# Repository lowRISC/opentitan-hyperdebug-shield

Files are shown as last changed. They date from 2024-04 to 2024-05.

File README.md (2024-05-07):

# OpenTitan

OpenTitan logo

## About the project

See the [OpenTitan site](https://opentitan.org/) and [OpenTitan docs](https://opentitan.org/book) for more information about the project.

## About this repository

This repository contains the manufacturing files for the OpenTitan Hyperdebug Shield development platform, codenamed 'TEACUP' created as part of the OpenTitan project. It exists to enable collaboration across partners participating in the OpenTitan project.

### What is the OpenTitan Hyperdebug Shield?

hyp_ot

The OpenTitan Hyperdebug Shield, codenamed TEACUP, is a development board which connects to the STM32F552 Nucleo, (ST Part Number: [NUCLEO-L552ZE-Q](https://www.st.com/en/evaluation-tools/nucleo-l552ze-q.html). This development board allows for developing and provisioning of Nuvoton's implementation of OpenTitan, the NPCR100T.

The OpenTitan Hyperdebug Shield contains:
- 1x BOYD Corp. 718-SW08105-508-B1 9x9 0.5mm BGA socket (Socket Optional)
- 1x DEDIPROG TECHNOLOGY SOK-SPI-WSON68-L WSON68 flash socket (Socket Optional)
- 1x USBC, USB 2.0 connector (without PD/BC1.2)
- 2x MICROCHIP TECHNOLOGY INC. PAC1954T-E/4MX
- 1x ISSI IS31FL3205-QFLS4-TR LED Driver
- 4x RGB LEDs
- 4x Zio connectors
- 1x JTAG connector

### Block Diagram

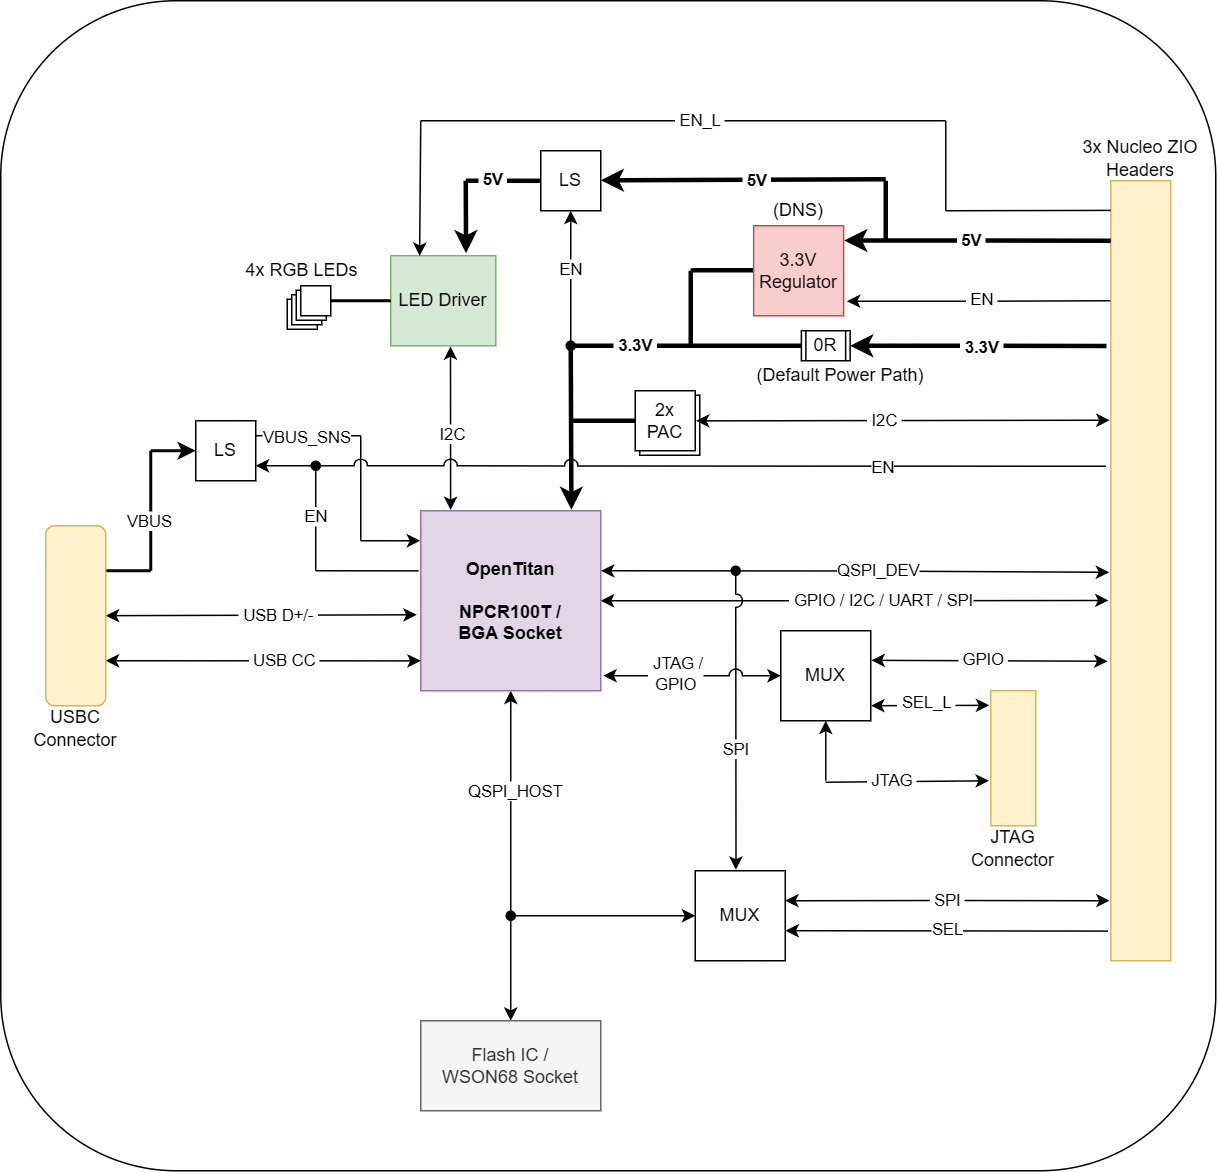
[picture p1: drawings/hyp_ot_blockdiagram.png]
hyp_ot_bd


Note: 
Sockets are provided for both the NPCR100T as well as the WSON8 flash. 
Both sockets are optional, giving the ability to have the NPCR100T as well as the WSON68 flash soldered down instead.

## Repository Directory

The project contains manufacturing documentation of the OpenTitan Hyperdebug Shield. 
For detailed documentation of the software and tooling, please see [docs.opentitan.org](https://docs.opentitan.org/).

### Projects top-level directory

    .
    ├── bom                     # Bill Of Materials
	├── drawings                # Schematics and Assembly Drawings
	├── gerbers                 # Gerbers, Drill Drawings and other output files for PCB Fab and Assembly
    ├── images                  # Images used on this repository
    └── README.md				# This file

## How to contribute

Have a look at [CONTRIBUTING](https://github.com/lowRISC/opentitan/CONTRIBUTING.md) and our [documentation on project organization and processes](./doc/project_governance/README.md) for guidelines on how to contribute code to this repository.

## Licensing

Unless otherwise noted, everything in this repository is covered by the Apache License, Version 2.0 (see [LICENSE](https://github.com/lowRISC/opentitan-hyperdebug-shield/LICENSE) for full text).

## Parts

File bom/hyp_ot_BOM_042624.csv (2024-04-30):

TITLE: Bill of Materials
DESIGN: hyp_ot
DATE: 04/26/2024
Ref Des | Qty | DESCR | MFGR | MFGR_PN | BOM_IGNORE
C24 | 1 | CAP, CER, X5R, 1uF, 10%, 10V, 0402, 0.55mm | ? | ? | DNS
C42 | 1 | CAP, CER, X5R, 1uF, 10%, 10V, 0402, 0.55mm | ? | ? | ?
C4,C7,C10,C13,C14,C15,C17,C18,C28,C29,C30,C31,C32,C34,C37 | 15 | CAP, CER, X7R, 0.1uF, 10%, 16V, 0402, 0.55mm | ? | ? | ?
C19,C23,C41 | 3 | CAP, CER, X7R, 0.1uF, 10%, 16V, 0402, 0.55mm | ? | ? | DNS
C20,C25,C33,C36,C38,C39,C40 | 7 | CAP, CER, X5R, 4.7uF, 20%, 10V, 0402, 0.65mm | ? | ? | ?
C27 | 1 | CAP, CER, X7R, 0.01uF, 10%, 25V, 0402, 0.56mm | ? | ? | DNS
C8 | 1 | CAP, CER, X7R, 0.01uF, 10%, 25V, 0402, 0.56mm | ? | ? | ?
C21,C22 | 2 | CAP, CER, X5R, 220pF, 10%, 25V, 0201, 0.33mm | ? | ? | DNS
C35 | 1 | CAP, CER, X5R, 4.7uF, 10%, 35V, 0603, 1.00mm | ? | ? | ?
J18 | 1 | CONN, HDR, VERT, 2x10 PIN, 2.54mmP, GOLD, SMD, 9.19mm | SAMTEC INC | HTST-110-01-L-DV-P-TR | ?
J1 | 1 | CONN, SKT, USB, TYPE C, RA, 24 PIN, 0.5mmP, GOLD, SMD, 3.38mm | AMPHENOL | 12401832E402A | ?
J21 | 1 | CONN, HDR, VERT, 6 PIN, 2.54mmP, GOLD, SMD, 5.84mm | SAMTEC INC | TSM-106-01-L-SV | DNS
J14,J22 | 2 | CONN, SKT, SMA, VERT, 1 PIN, 50R, GOLD, TH, 9.601mm | SAMTEC INC | SMA-J-P-H-ST-TH1 | DNS
J9,J10,J11,J12,J13,J15,J16 | 7 | CONN, HDR, UNSHRD, VERT, 1x2 PIN, 2.54mmP, TIN, TH, 8.73mm | FCI | 68000-402HLF | DNS
J19,J20 | 2 | CONN, B2B, SKT, RA, 2x6 PIN, 2.54mmP, GOLD, TH, 4.95mm | SAMTEC INC | SSW-106-02-F-D-RA | ?
J5 | 1 | CONN, SKT, SPI FLASH, WSON8 6x8, 8, 1.27mmP, Nickel/Gold, SMD, 9.85x10.20mm, 3.00mm | Dediprog Technology | SOK-SPI-WSON68-L | ?
CN8 | 1 | CONN, HDR, VERT, 2x8 PIN, 2.54mmP, GOLD, TH, 5.21mm | SAMTEC INC | TSW-108-16-G-D | ?
CN7 | 1 | CONN, HDR, VERT, 2x10 PIN, 2.54mmP, GOLD, TH, 5.31mm | SAMTEC INC | TSW-110-16-G-D | ?
CN9 | 1 | CONN, HDR, VERT, 2x15 PIN, 2.54mmP, GOLD, TH, 5.31mm | SAMTEC INC | TSW-115-16-G-D | ?
CN10 | 1 | CONN, HDR, VERT, 2x17 PIN, 2.54mmP, GOLD, TH 5.13mm | SAMTEC INC | TSW-117-16-G-D | ?
U8 | 1 | IC, AMP, R2R OUT, DUAL, 1.7-5.5Vin, 4.5mVoff, 450nA, VSSOP-8, 1.10mm | TEXAS INSTRUMENTS INC | TLV8802DGKR | DNS
U13,U15 | 2 | IC, LOGIC, LVC, BUFFER, TRI-STATE, AH ENABLE, 1.65-5.5Vcc, 3.4ns@5V/15pF, 32mA, SC70-5, 1.10mm | TEXAS INSTRUMENTS INC | SN74LVC1G126DCKR | ?
U14 | 1 | IC, LED DRIVER, RGB, 12-CH, I2C, 2.7-5.5V, Current 38 mA (max) QFN-20, 0.75mm | ISSI | IS31FL3205-QFLS4-TR | ?
U10,U11 | 2 | IC, ANALOG SW, MUX/DEMUX, 1:2, SPDT, 6-CH, 1.65-3.6Vcc, 100mA IS, 6.2Ohm MAX Ron, 240MHz, WQFN-24, 0.8mm | TEXAS INSTRUMENTS INC | TS3A27518ERTWR | ?
U1,U4 | 2 | IC, PWR, MONITOR, CURRENT, 4-CH, ADC, 16-BIT, I2C/SMBus, 2.7-5.5Vdd, QFN-16, 0.90mm | MICROCHIP TECHNOLOGY INC | PAC1954T-E/4MX | ?
U9 | 1 | IC, PWR, REG, LDO, AH ENABLE, 1.2-5.5Vin, 3.3Vout, 2%, 300mA, TSOT23-5, 1.00mm | Richtek Technology Corporation | RT9078-33GJ5 | DNS
U301 | 1 | IC, FLASH, NOR, SPI, 128Mb, 3.3V, WSON-8, 0.80mm | Winbond Electronics | W25Q128JVEIM | ?
DS5,DS9,DS10,DS11 | 4 | LED, RGB, R-619/G-518/B-467nm, R-450/G-710/B-140mcd, 120 DEG, R-1.8V/G-2.8V/B-2.8V@20mA, SMD-6, 1.6x1.6mm, 0.60mm | Everlight Electronics Co., Ltd | 19-337C/RSBHGHC-A91/4T | ?
U12 | 1 | IC, PWR, LOAD SW, AH ENABLE, 1.05-5.5Vin, 2A, 37mOhm@5Vin/200mA, DSBGA-4, 0.50mm | TEXAS INSTRUMENTS INC | TPS22915BYFPR | DNS
U7 | 1 | IC, PWR, LOAD SW, AH ENABLE, 1.05-5.5Vin, 2A, 37mOhm@5Vin/200mA, DSBGA-4, 0.50mm | TEXAS INSTRUMENTS INC | TPS22915BYFPR | ?
D4,D6 | 2 | DIODE, TVS, BI, ESD PROT, 5Vrwm, 10Vbr, 12.8Vcl, 2A Ipp, 6pF, SOD962-2, 0.32mm | Nexperia | PESD5V0V1BDSF,315 | ?
R62,R63,R66,R67,R109,R110 | 6 | RES, 0.0, 1/20W, 0201, 0.26mm | ? | ? | DNS
R69,R70,R119,R153,R154 | 5 | RES, 0.0, 1/20W, 0201, 0.26mm | ? | ? | ?
R107,R115 | 2 | RES, 10K, 5%, 1/20W, 0201, 0.26mm | ? | ? | DNS
R163,R164,R165,R166,R167,R168,R169 | 7 | RES, 0.0, 1/16W, 0402, 0.40mm | ? | ? | ?
R17,R24,R26,R59,R146,R175 | 6 | RES, 1M, 1%, 1/10W, 0603, 0.60mm | ? | ? | ?
R97 | 1 | RES, 100, 1%, 1/16W, 0402, 0.40mm | ? | ? | DNS
R23,R25,R27,R155 | 4 | RES, 4.99K, 1%, 1/16W, 0402, 0.40mm | ? | ? | ?
R118,R160 | 2 | RES, 22, 5%, 1/16W, 0402, 0.40mm | ? | ? | ?
R68,R71 | 2 | RES, 2M, 5%, 1/16W, 0402, 0.40mm | ? | ? | DNS
R44,R47,R122 | 3 | RES, 100K, 1%, 1/10W, 0603, 0.55mm | ? | ? | ?
R170,R190 | 2 | RES, 100K, 1%, 1/10W, 0603, 0.55mm | ? | ? | DNS
R7,R11,R14,R15,R18,R19,R21,R22,R135,R136 | 10 | RES, 1K, 1%, 1/10W, 0603, 0.60mm | ? | ? | ?
R42,R43,R48,R49,R50,R51,R58,R75,R76,R77,R78,R83,R84,R85,R86,R87,R93,R95,R96,R100,R101,R105,R106,R113,R117,R143,R151,R162,R176,R192 | 30 | RES, 0.0, 1/10W, 0603, 0.60mm | ? | ? | ?
R116,R150,R191 | 3 | RES, 0.0, 1/10W, 0603, 0.60mm | ? | ? | DNS
R64,R65 | 2 | RES, 5.11K, 1%, 1/16W, 0402, 0.40mm | ? | ? | DNS
R173 | 1 | RES, 7.5K, 1%, 1/16W, 0402, 0.40mm | ? | ? | ?
R120,R121,R125,R134,R145 | 5 | RES, 10K, 5%, 1/10W, 0603, 0.55mm | ? | ? | DNS
R123,R124,R131,R139,R140,R142,R161,R174,R189,R193 | 10 | RES, 10K, 5%, 1/10W, 0603, 0.55mm | ? | ? | ?
R177,R179,R180,R182,R183,R185,R186,R188 | 8 | RES, 33, 5%, 1/10W, 0603, 0.55mm | ? | ? | ?
R41,R114 | 2 | RES, 499, 1%, 1/10W, 0603, 0.55mm | ? | ? | ?
R178,R181,R184,R187 | 4 | RES, 75, 0.1%, 1/10W, 0603, 0.55mm | ? | ? | ?
R79,R80,R81,R82,R91,R94 | 6 | RES, 0.5, 1%, 1/10W, 0603, 0.60mm | ? | ? | ?
Q9,Q10 | 2 | XSTR, MOSFET, N-CH, DUAL, 50Vds, 200mA Id, 6 Ohm@1.8Vgs/10mA, 300mW, 6pF, SOT563-6, 0.60mm | DIODES INC. | DMN5L06VK-7 | ?
D1,D2 | 2 | DIODE, ZENER, 0.9Vf @ 10mA, 5.6Vz, 5%, 50uA Izt, 300mW, SOD323, 1.1mm | Nexperia | BZX38450-C5V6 | DNS
D5 | 1 | DIODE, ZENER, 0.9Vf @ 10mA, 5.6Vz, 5%, 50uA Izt, 300mW, SOD323, 1.1mm | Nexperia | BZX38450-C5V6 | ?
U2 | 1 | Mating BGA socket for G660-00537-00 | Nuvoton Technology | NPCR100T | ?
 | 196

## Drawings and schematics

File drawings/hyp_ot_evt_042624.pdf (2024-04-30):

D

7

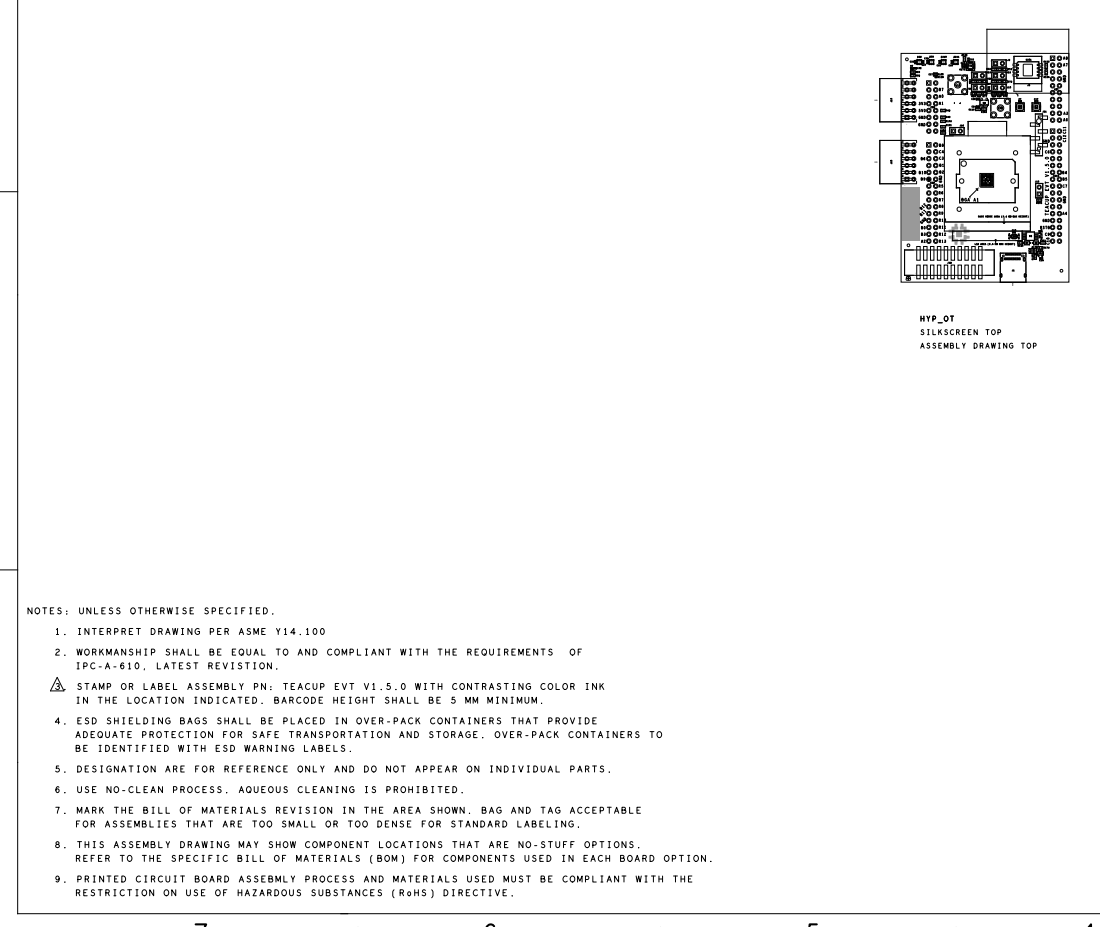
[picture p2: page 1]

INITIAL
CHANGED ASSEMBLY NPTE WITH G650 P/N
EVT UPREV WITH BUG AND DESIGN FIX

BASE HINGE AREA (3,4 MM MAX HEIGHT)

LID AREA (6.4 MM MAX HEIGHT)

NOTES: UNLESS OTHERWISE SPECIFIED.

1. INTERPRET DRAWING PER ASME Y14.100

3. STAMP OR LABEL ASSEMBLY PN: TEACUP EVT V1.5.0 WITH CONTRASTING COLOR INK

IN THE LOCATION INDICATED. BARCODE HEIGHT SHALL BE 5 MM MINIMUM.

4. ESD SHIELDING BAGS SHALL BE PLACED IN OVER-PACK CONTAINERS THAT PROVIDE

ADEQUATE PROTECTION FOR SAFE TRANSPORTATION AND STORAGE. OVER-PACK CONTAINERS TO

BE IDENTIFIED WITH ESD WARNING LABELS.

5. DESIGNATION ARE FOR REFERENCE ONLY AND DO NOT APPEAR ON INDIVIDUAL PARTS.

6. USE NO-CLEAN PROCESS. AQUEOUS CLEANING IS PROHIBITED.

7. MARK THE BILL OF MATERIALS REVISION IN THE AREA SHOWN. BAG AND TAG ACCEPTABLE

FOR ASSEMBLIES THAT ARE TOO SMALL OR TOO DENSE FOR STANDARD LABELING.

8. THIS ASSEMBLY DRAWING MAY SHOW COMPONENT LOCATIONS THAT ARE NO-STUFF OPTIONS.

REFER TO THE SPECIFIC BILL OF MATERIALS (BOM) FOR COMPONENTS USED IN EACH BOARD OPTION.

9. PRINTED CIRCUIT BOARD ASSEBMLY PROCESS AND MATERIALS USED MUST BE COMPLIANT WITH THE

RESTRICTION ON USE OF HAZARDOUS SUBSTANCES (RoHS) DIRECTIVE.

D

7

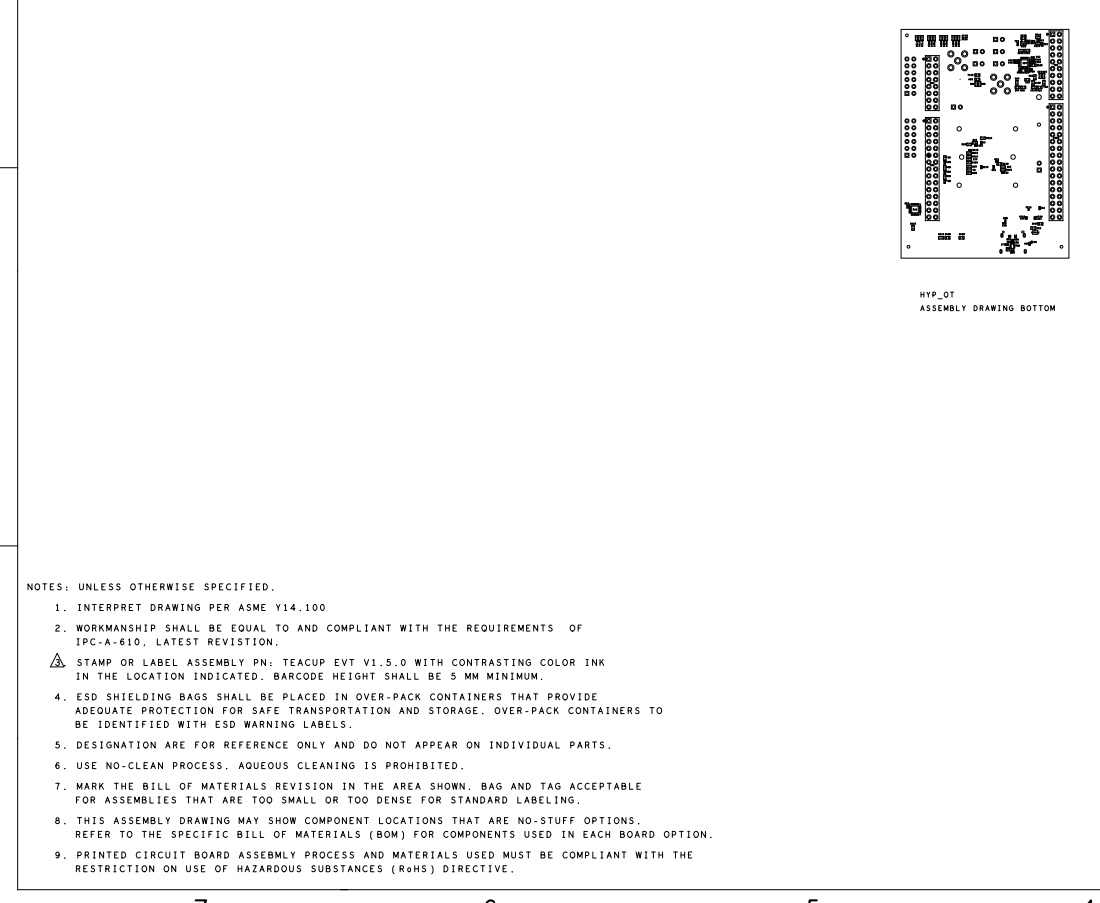
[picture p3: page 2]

INITIAL
CHANGED ASSEMBLY NPTE WITH G650 P/N
EVT UPREV WITH BUG AND DESIGN FIX

NOTES: UNLESS OTHERWISE SPECIFIED.

1. INTERPRET DRAWING PER ASME Y14.100

3. STAMP OR LABEL ASSEMBLY PN: TEACUP EVT V1.5.0 WITH CONTRASTING COLOR INK

IN THE LOCATION INDICATED. BARCODE HEIGHT SHALL BE 5 MM MINIMUM.

4. ESD SHIELDING BAGS SHALL BE PLACED IN OVER-PACK CONTAINERS THAT PROVIDE

ADEQUATE PROTECTION FOR SAFE TRANSPORTATION AND STORAGE. OVER-PACK CONTAINERS TO

BE IDENTIFIED WITH ESD WARNING LABELS.

5. DESIGNATION ARE FOR REFERENCE ONLY AND DO NOT APPEAR ON INDIVIDUAL PARTS.

6. USE NO-CLEAN PROCESS. AQUEOUS CLEANING IS PROHIBITED.

7. MARK THE BILL OF MATERIALS REVISION IN THE AREA SHOWN. BAG AND TAG ACCEPTABLE

FOR ASSEMBLIES THAT ARE TOO SMALL OR TOO DENSE FOR STANDARD LABELING.

8. THIS ASSEMBLY DRAWING MAY SHOW COMPONENT LOCATIONS THAT ARE NO-STUFF OPTIONS.

REFER TO THE SPECIFIC BILL OF MATERIALS (BOM) FOR COMPONENTS USED IN EACH BOARD OPTION.

9. PRINTED CIRCUIT BOARD ASSEBMLY PROCESS AND MATERIALS USED MUST BE COMPLIANT WITH THE

RESTRICTION ON USE OF HAZARDOUS SUBSTANCES (RoHS) DIRECTIVE.

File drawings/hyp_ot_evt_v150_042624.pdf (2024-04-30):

## THIS BOARD CONNECTS TO A MAINBOARD USING ZIO HEADERS CN7-CN10

## NOTES:

## MAIN POWER IS SOURCED FROM THE MAINBOARD THROUGH CN8

## TABLE OF CONTENTS

# (TEACUP)

# OpenTitan Hyperdebug Shield

2 | OPENTITAN
3 | SPI FLASH
4 | USB CONN
5 | LED DRIVER
6 | CURRENT SENSE
7 | HEADERS

1

| PAGE TABLE OF CONTENTS TITLE:
DESIGN: | DOC NUMBER: EVT-150-SCH | REV: 1.5.0
| AUTHOR: | PAGE: 1 OF 7 Brendan Bleker 1 OF 7 Thu Apr 11 17:03:11 2024
SHEET NO. | SHEET NAME

# TABLE OF CONTENTS

MODIFIED: LICENSED UNDER THE APACHE LICENSE, VERSION 2.0, SEE LICENSE.TXT FOR DETAILS.
1 | 5 | 7 | 13
15 | FLAT:

H

A

K | K
J | J
4 | 6 | 8 | 9
1 | 2 | 3 | 5 | 6 | 7 | 8 | 10 | 11 | 12 | 13 | 14 | 16

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
SPDX-LICENSE-IDENTIFIER: APACHE-2.0

COPYRIGHT LOWRISC CONTRIBUTORS.

## BGA SOCKET

## 718-SW08105-508-B1

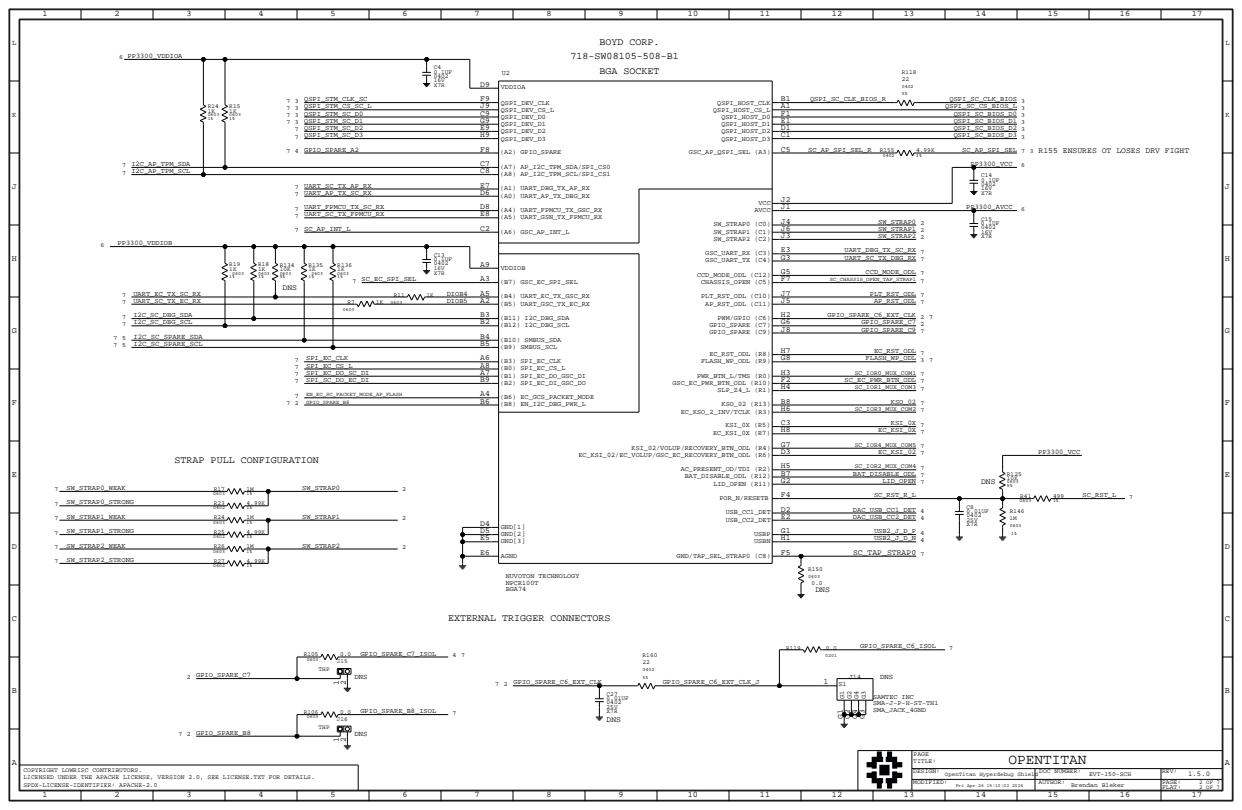
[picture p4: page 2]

OPENTITAN

OpenTitan Hyperdebug Shield
Brendan Bleker | 2 OF 7 Fri Apr 26 15:10:02 2024

TRACES TO REDUCE STUBS.

## TO PREVENT BOTH FROM BEING POPULATED AT THE SAME TIME

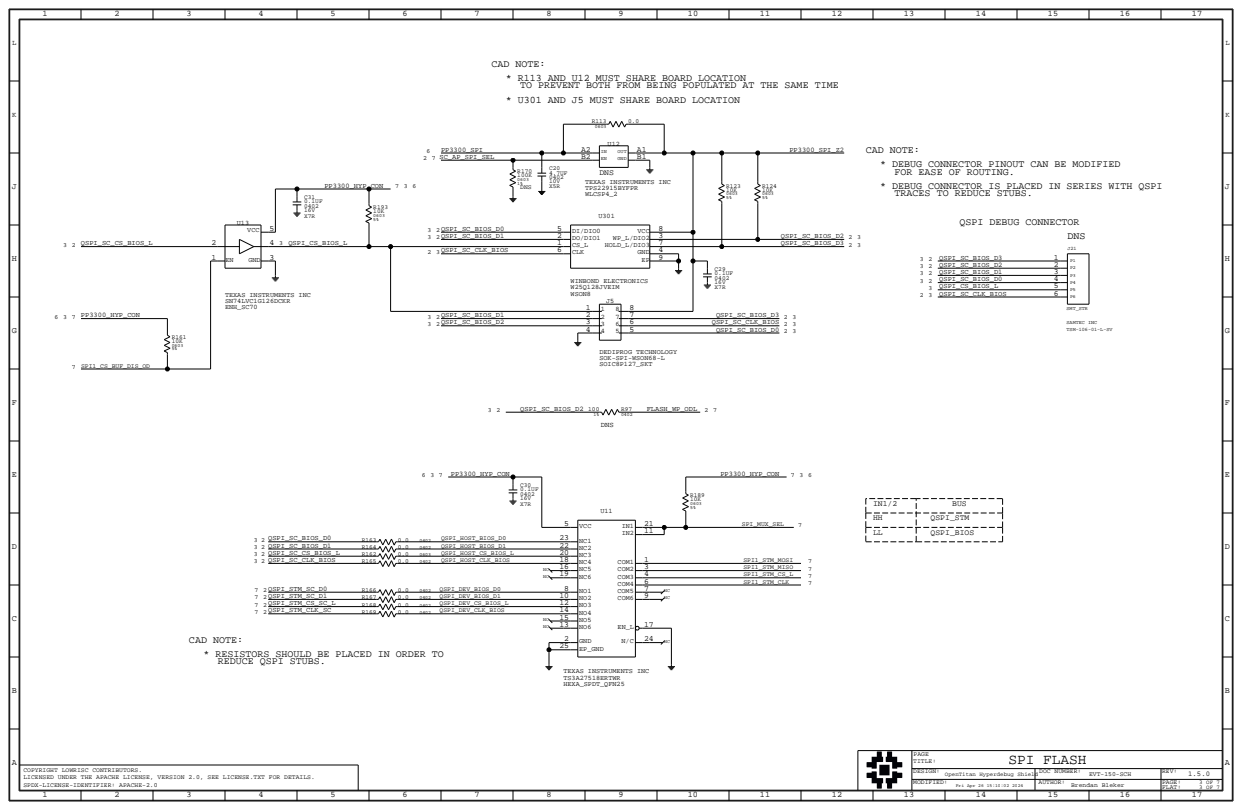
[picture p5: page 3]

CAD NOTE:
* R113 AND U12 MUST SHARE BOARD LOCATION
* U301 AND J5 MUST SHARE BOARD LOCATION

* DEBUG CONNECTOR PINOUT CAN BE MODIFIED
FOR EASE OF ROUTING.
* DEBUG CONNECTOR IS PLACED IN SERIES WITH QSPI

* RESISTORS SHOULD BE PLACED IN ORDER TO
REDUCE QSPI STUBS.

CC PROTECTION CIRCUITS.

## ONLY POPULATE ONE (Q9 OR U8) SOLUTION

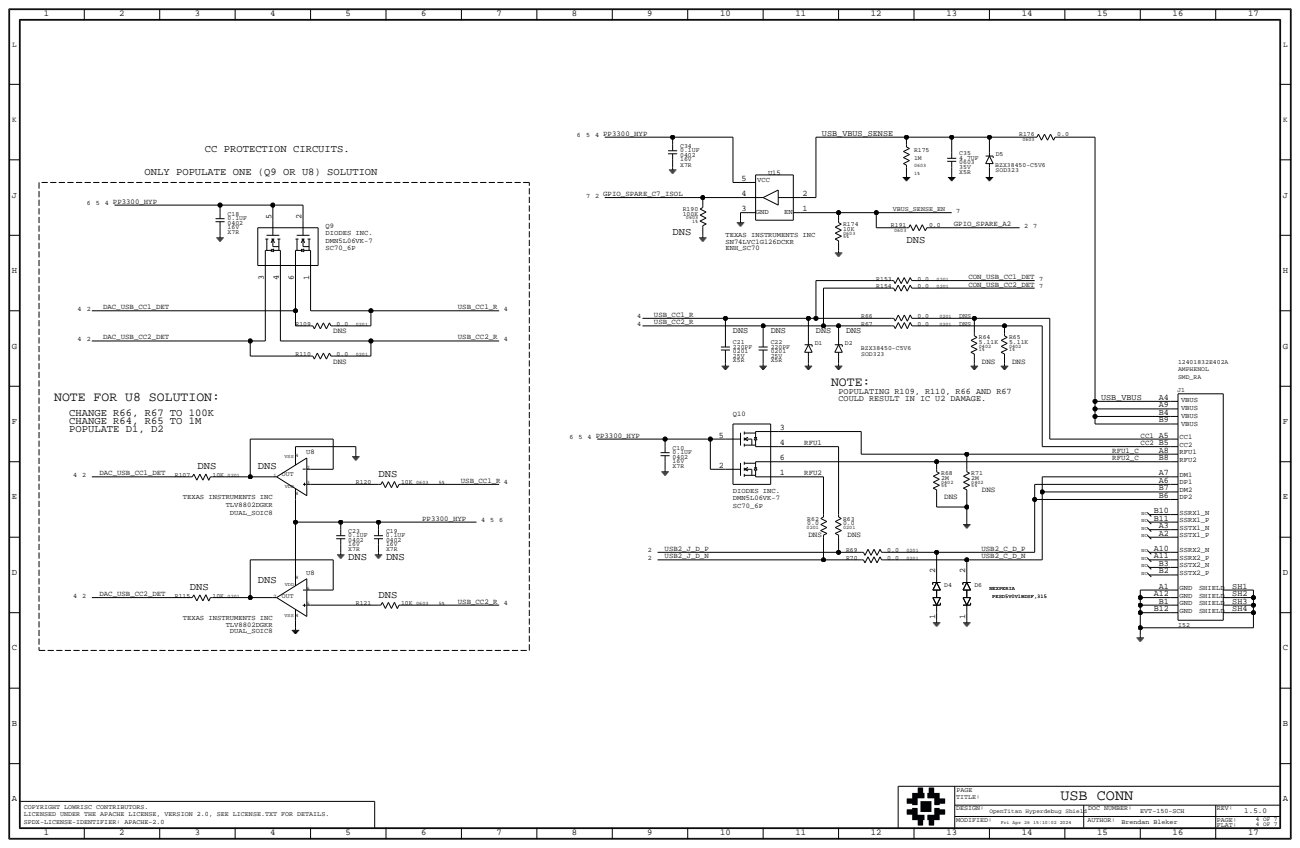
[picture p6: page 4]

A1
A12 | | SH2
B1 | | SH3
B12 | | SH4

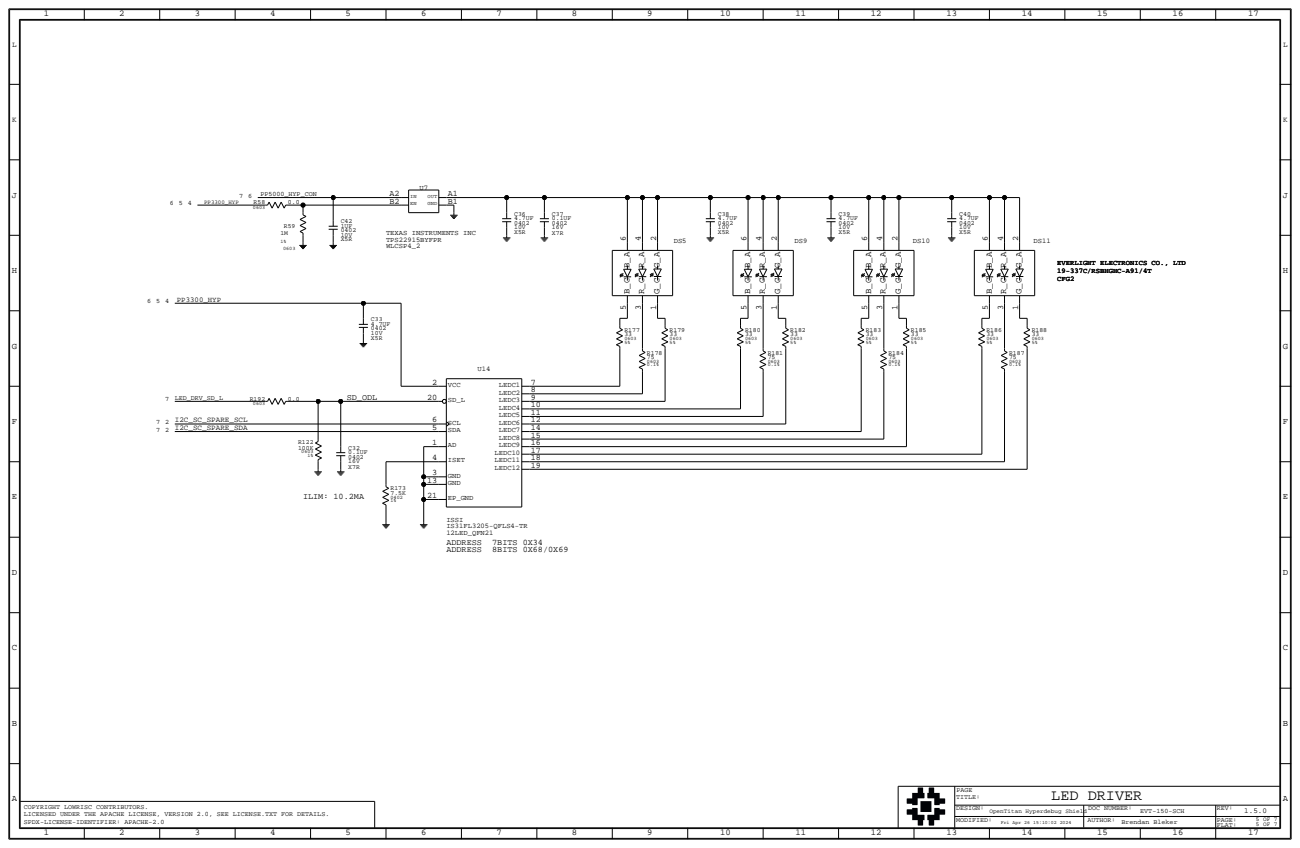
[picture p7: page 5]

EVERLIGHT ELECTRONICS CO., LTD

## DNS

## DNS 10V

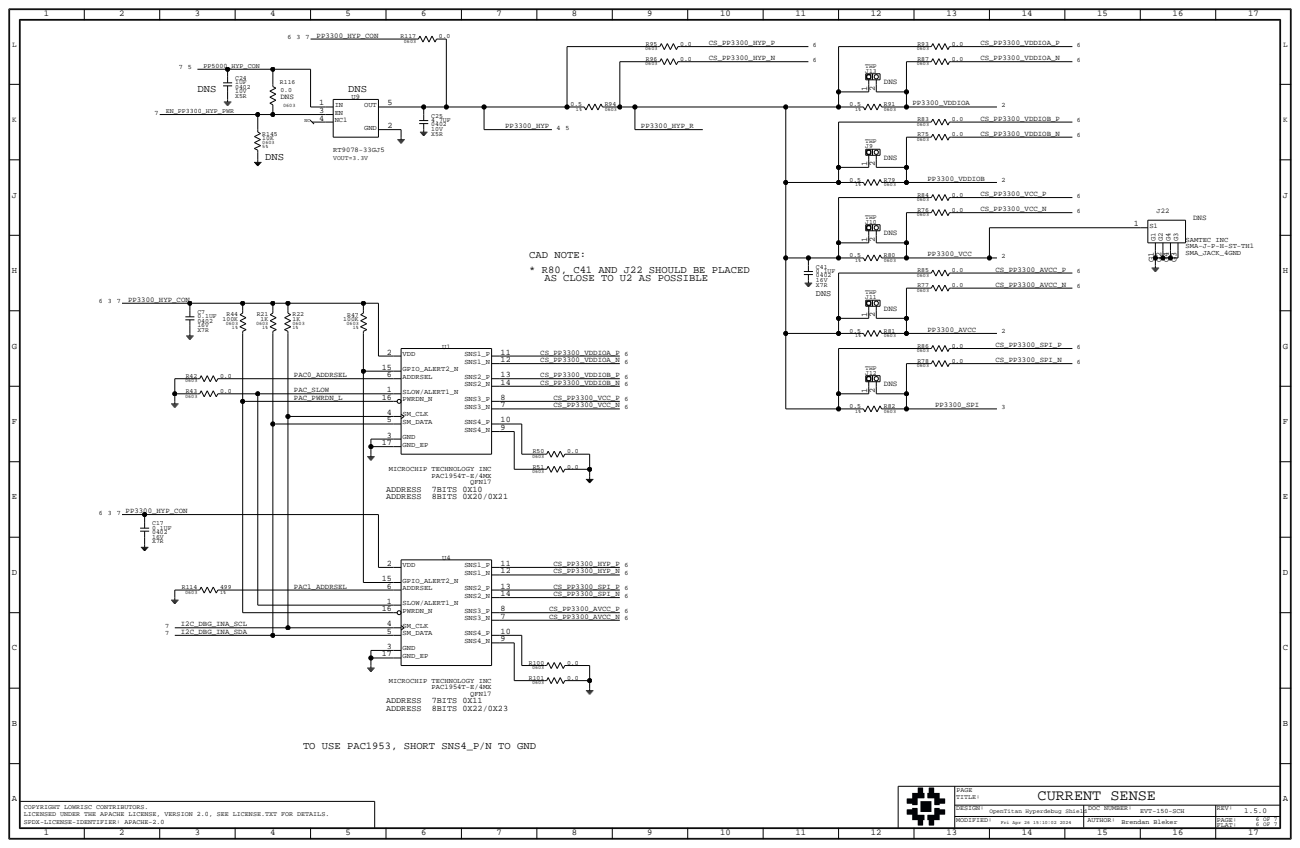
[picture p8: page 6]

CAD NOTE:
AS CLOSE TO U2 AS POSSIBLE * R80, C41 AND J22 SHOULD BE PLACED

TO USE PAC1953, SHORT SNS4_P/N TO GND

## DEFAULT

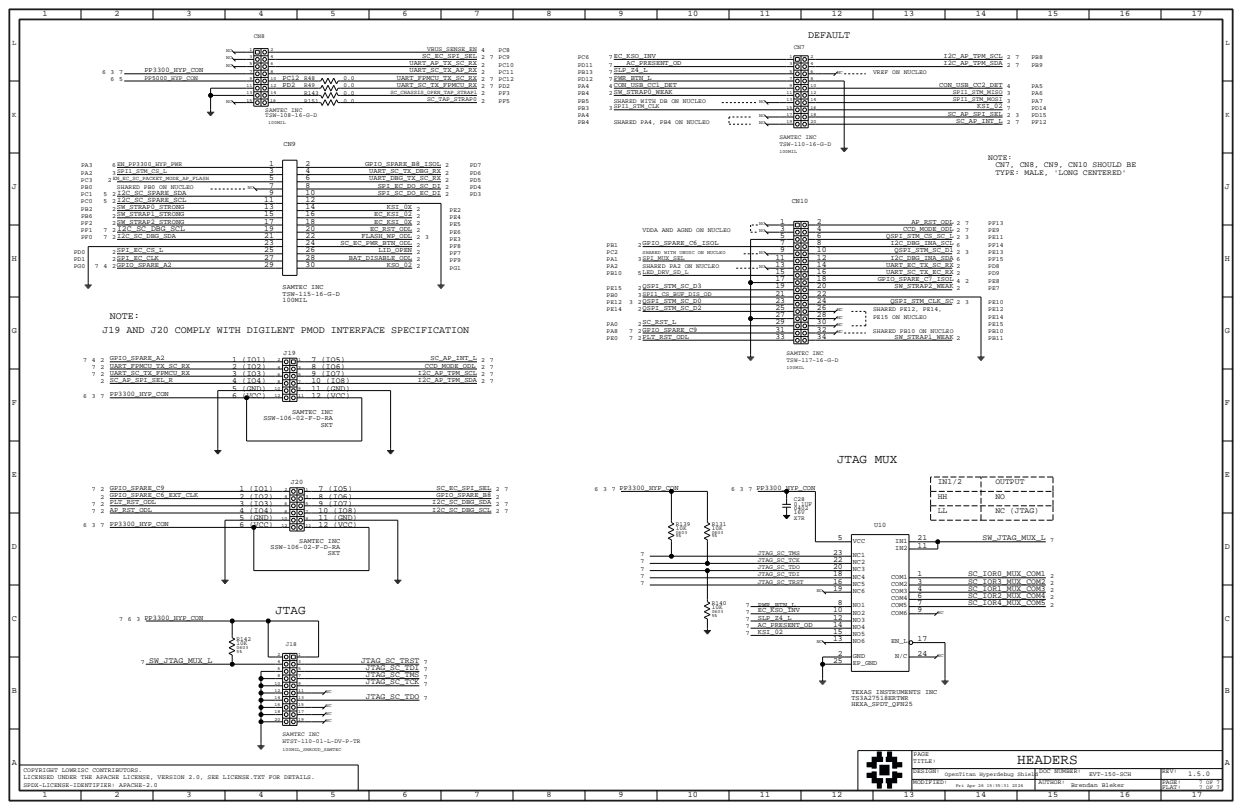
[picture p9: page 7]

13 | 14 R143
15 | 16

NOTE:
CN7, CN8, CN9, CN10 SHOULD BE
TYPE: MALE, 'LONG CENTERED'

SHARED WITH UBUSC ON NUCLEO
SPI_MUX_SEL

J19 AND J20 COMPLY WITH DIGILENT PMOD INTERFACE SPECIFICATION

IN1/2 | OUTPUT
HH | NO
LL | NC (JTAG)

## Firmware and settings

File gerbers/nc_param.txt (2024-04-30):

INTEGER-PLACES         5
DECIMAL-PLACES         5
X-OFFSET               0.000000
Y-OFFSET               0.000000
FEEDRATE               1
COORDINATES            ABSOLUTE
OUTPUT-UNITS           METRIC
TOOL-ORDER             INCREASING
REPEAT-CODES           YES
SUPPRESS-LEAD-ZEROES   YES
SUPPRESS-TRAIL-ZEROES  NO
SUPPRESS-EQUAL         NO
TOOL-SELECT            NO
OPTIMIZE_DRILLING      NO
ENHANCED_EXCELLON      NO
HEADER                 none
LEADER                 12
CODE                   ASCII
SEPARATE               NO
SEPARATE-ROUTING       NO
DRILLING               LAYER-PAIR
BACKDRILL              NO
CAVITY                 NO
COUNTER                NO
TOLERANCE_DRILL        NO
TOLERANCE_TRAVEL       NO
TOOL_SIZE              NO
ROTATION               NO
NON_STANDARD           YES
TOTAL_DRILL            NO
SEPARATE_SLOT          NO
SUPPRESS_TOLERANCE     YES
SUPPRESS_TOOLSIZE      YES
SUPPRESS_ROTATION      YES

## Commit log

2024-04-26 Adding initial files for EVT OpenTitan Hyperdebug Shield
    [art_param.txt, hyp_ot_BOM_042624.csv, nc_param.txt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]
2024-04-30 Update hyp_ot_evt_pickplace.txt
    Changed PN of headers to match BOM.
